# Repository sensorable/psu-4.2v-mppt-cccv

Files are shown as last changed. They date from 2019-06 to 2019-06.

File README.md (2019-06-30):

# MPPT 4.2v Li-Ion charger and SBC PSU
#### For use with Sensorable Open Source Camera v.1

The PSU board combines an MPPT (Multiple Point Power Tracking) solar charger, 4.2v battery IO port and a protected 4.2v output to power the main camera board.

 > This design has been **assembled with PCBA and successfully used** in temperate climate for over a year. 

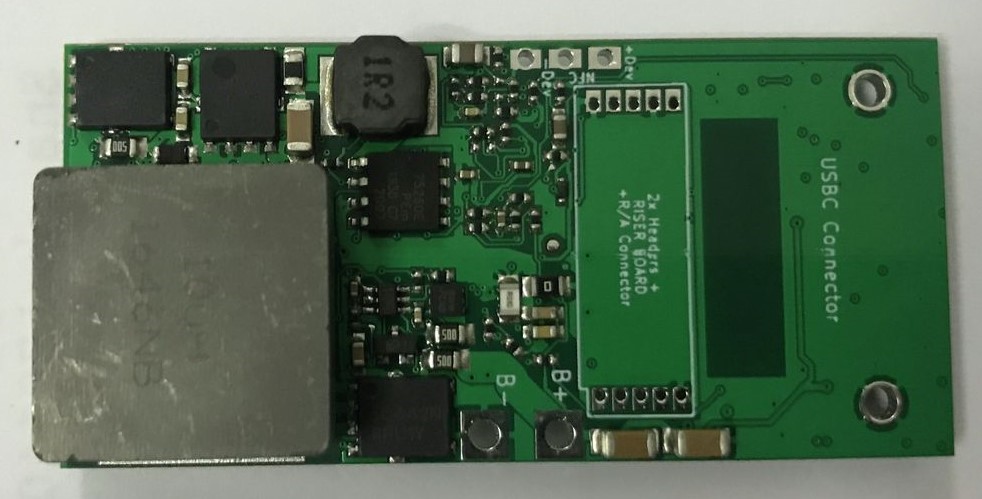
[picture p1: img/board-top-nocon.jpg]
top-nocon
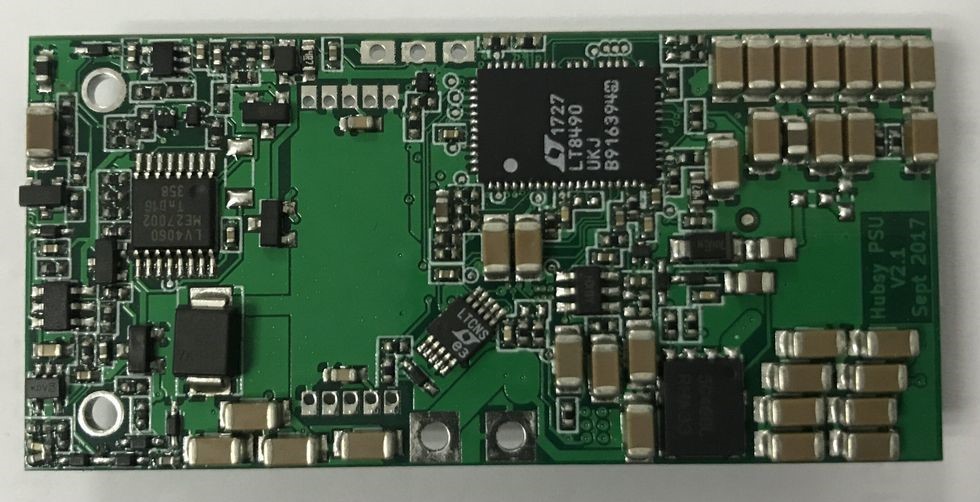
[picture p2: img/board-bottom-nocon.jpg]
bottom-nocon
 

## Specification

* **Max input working voltage:** 24V
* **Min input working voltage:** 12v
* **Max input current:** 2.5A
* **Max output current:** 6.5A
* **Max operating current:** 2A
* **Ripple:** <50mVpp nominal steady state
* **Size**: 65mm x 27mm x 15mm

#### Protection

* **Shunt Input protection:** Bipolar Zener diode, 24V working voltage, clamps to 38.9V @ 15.5A; For ESD and shunt of high-voltage surges. First line of defence. 
* **Series Input protection:** 24V working voltage 31.6V clamp, 2.5A max current. Series FETs and associated circutry will: 
Block reverse voltage. Limit current during hot-plug (for no sparks) and during surges. 
If prolonged over-voltage surge is detected charger is disabled (w/ auto-restart after surge passes) to limit power dissipated in series FETs. 
Precision over-voltage clamp (31.6V) protects switching FETs from over-voltage.  
* **Overload protection, Vbat:** None, rely on BMS. Charge current and voltage is limited by charger. 
* **Overload protection, Vout:** 4A lim; 4.5ms time constant. Retry after >500ms. Short-circuit safe.
* **Reverse polarity protection, Vin:** Safe DC voltage of +/-24V.
* **Reverse polarity protection, Vbat:** None. Charger will not attempt to charge a reversed battery but other electronics would be damaged. Batt reverse protection must be placed on BMS. 
* **Overheating protection:** Charge only when safe for Li-Ion 0C-45C, and adjust current/voltage based on temp (LT8490 feature). 
* **Electrostatic protection:** ESD/Surge protection on Input voltage, Heartbeat input, Battery voltage, Device voltage. 

## Overview

The PSU is built around [LT8490](https://www.analog.com/en/products/lt8490.html) buck-boost switching regulator battery charger with CC/CV modes and MPPT for solar input.

The purpose of the PSU is to provide a compromise between fast charging and efficient low light charging a 4P/5P/6P Li-Ion battery pack powering the main board.
The PSU incurs more losses during charging (18v -> 4.2v) to minimizes losses during discharge (4.2v direct output).
`Vout` port has an analog restart circuit for a hard reboot of the main device every 18 - 24 hrs.

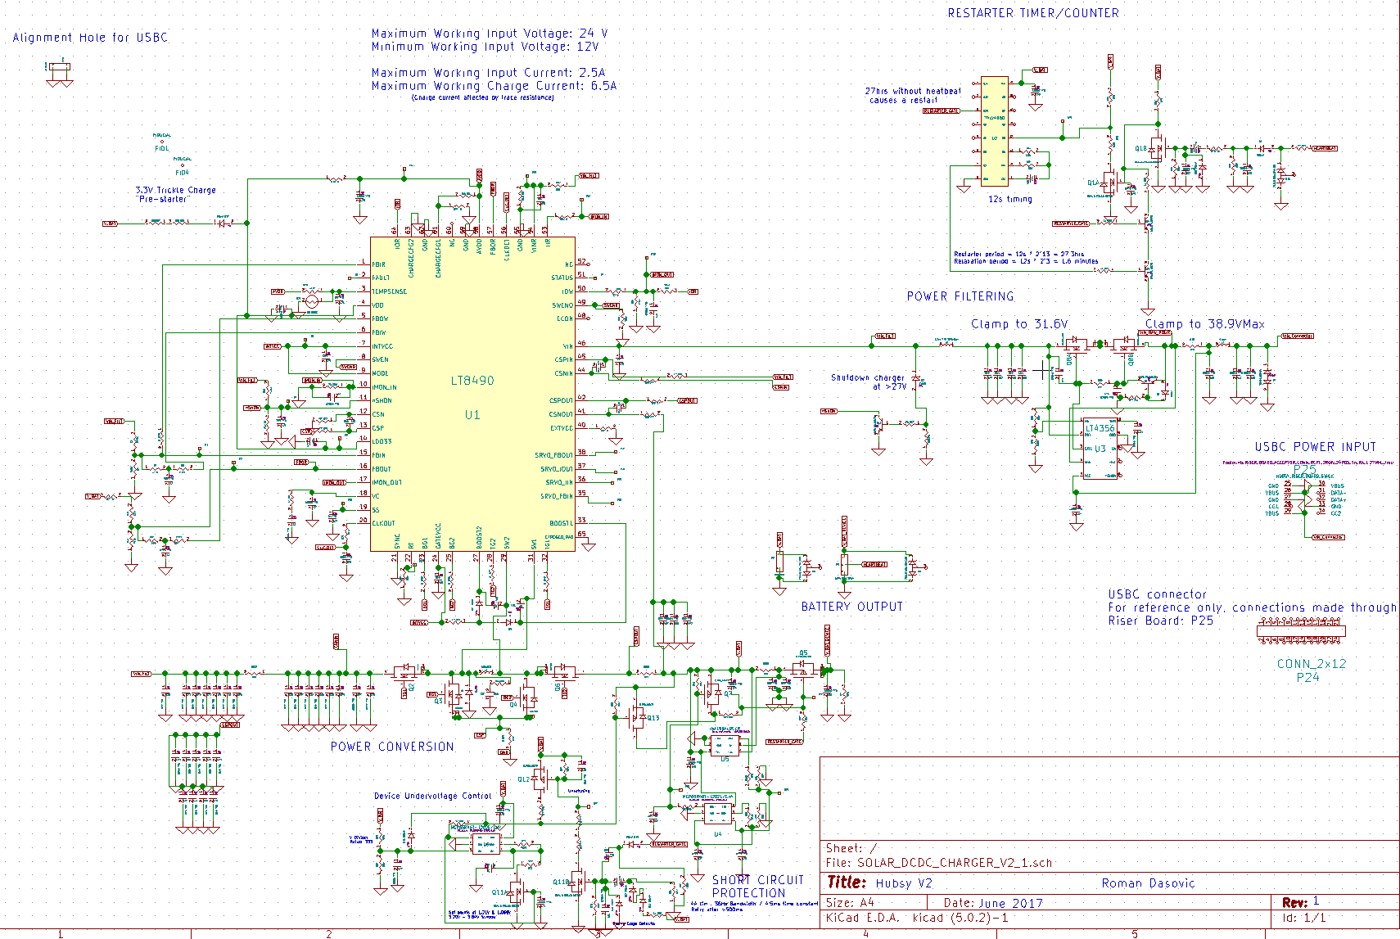
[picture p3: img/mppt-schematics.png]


#### Heat dissipation

Switching MOSFETs, the main coil and other parts of the board require heat sinking. The board itself has more copper than the electrical design requires to help dissipate the heat, but it's not enough with passive cooling inside an enclosure. Additional heat dissipation was achieved by potting the entire assembly in a metal frame with [Electrolube ER2074](https://www.electrolube.com/products/polyurethane-epoxy-resins/er2074/resins_epoxy/) epoxy resin. It produced a sealed unit that could be exposed outside the enclosure. The best result was achieved by potting the PSU inside a standard size Al U-channel.

## Features

#### Pre-starter

Most battery protection systems require external voltage to be applied for their MOSFETs to open In/Out. On the other hand, LT8490 will not attempt to charge the battery until it measures the voltage. If the battery pack gets disconnected by its protection MOSFETs it will be restarted by a 3.3V trickle charge circuit. That voltage is enough to unlock the BMS.

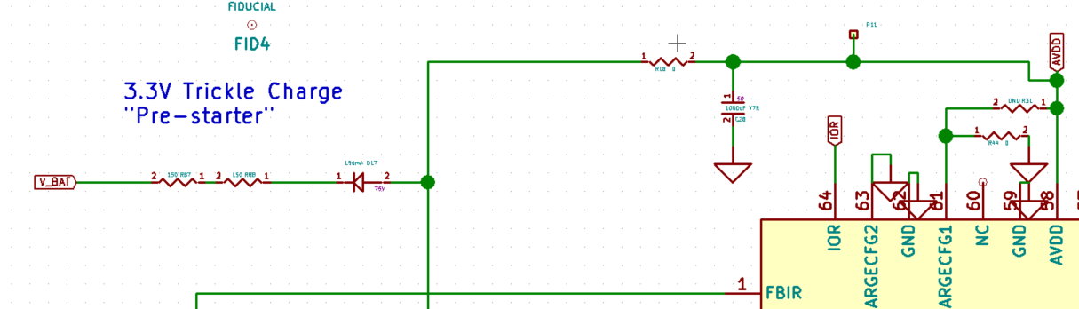
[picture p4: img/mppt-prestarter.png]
prestarter


#### Under-voltage protection

G935 board can function with Vin > 3.4v. However, the initial draw from a 3.4v battery brings the voltage down to below that. This initiates a start-abort boot cycle that drains the battery and may even damage the board. This PSU has a special undervoltage control circuit built that disables the Vout to the device until the battery voltage reaches at least 3.7v. Once operational, the device will continue until the voltage drops to 3.20V. When off, the device is latched off until the restarter circuit triggers or the battery voltage rapidly rises (a freshly inserted battery, a freshly reset BMS). 

**Consider these scenarios:**

* battery connected, Vbat < 3.7v -> Vout = Vbat momentarily, then latches off to Vout = 0V. 
* battery connected, Vbat > 3.7v -> Vout = Vbat; operational
* battery discharging, 3.2v < Vbat < 3.7v -> Vout = Vbat; operational
* battery discharging, reboot, Vbat < 3.7v -> Vout = Vbat momentarily, then latches off to Vout = 0V. 
* battery charged to 3.7v, reboot -> Vout = Vbat; operational

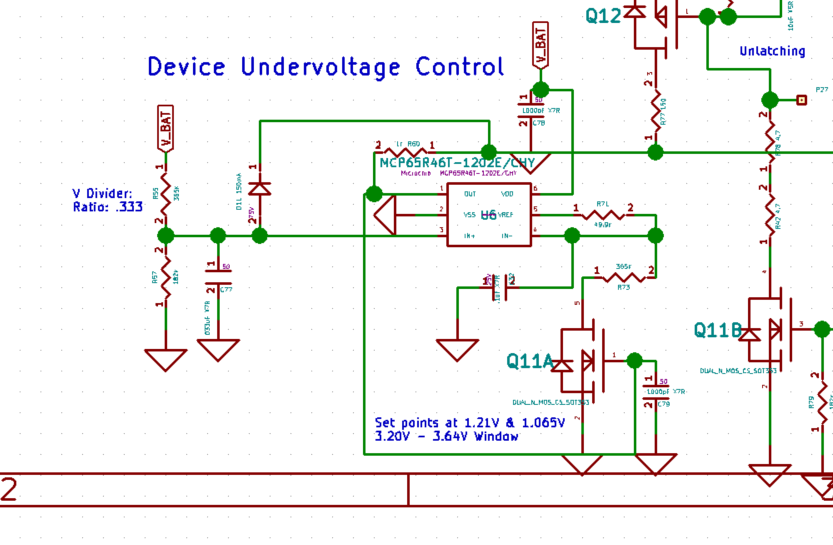
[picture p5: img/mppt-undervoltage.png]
undervoltage


#### Restarter

Given the remote nature of the PSU deployment a **hard reboot** on a schedule (approx every 27hrs) safeguards from the main board freezing for whatever reason. It is the equivalent of turning the power off for a few seconds. 

A restarter **heartbeat** wire (P3.2) can be connected to an NFC pin on G935 boards to prevent the restart. When NFC is enabled G935 sends a short burst of pulses to the restarter resetting the timer.

**Heartbeat signal requirements:** Rising edge or edges (such as sine waves from NFC) with >2V positive peaks. Must be present for >1ms.  Then, must relax for  2s < t << 27 hrs.  For example, send a 1ms NFC pulse every 5s/5min/5hour. 
Can also be operated with DC with similar timing/voltage requirements.  
Will not work with consistent output, must be pulsed.  

#### Connectors

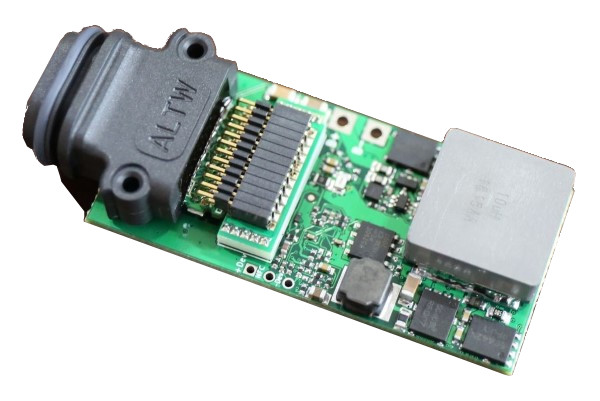
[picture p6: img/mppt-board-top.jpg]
board-top
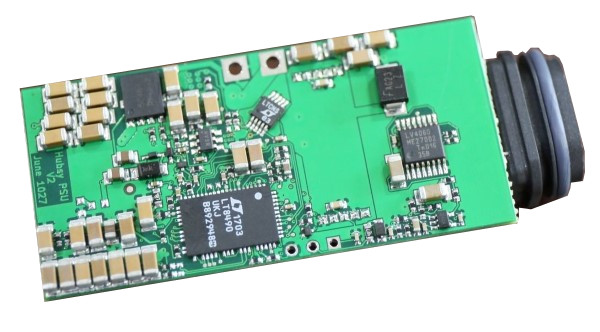
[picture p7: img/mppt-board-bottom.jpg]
board-bottom
 

#### IP68 USB-C connector

 input from a solar panel or a wall charger. This connector provides a sealed connection up to 2A per contact and remains waterproof when decoupled. Amphenol LTW part number: UC-31PFFP-QS8001. Mates with UC-20AMM-QA8A01 or similar.

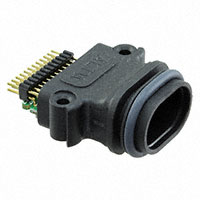
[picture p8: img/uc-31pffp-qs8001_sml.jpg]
usbc
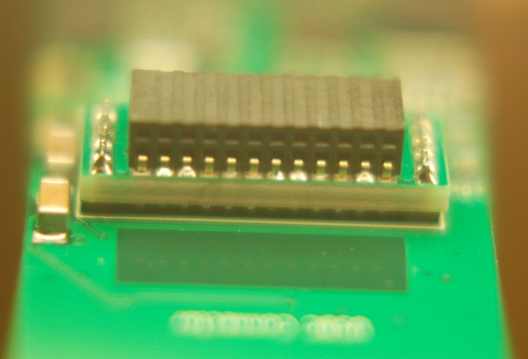
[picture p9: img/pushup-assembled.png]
pushup
 

**Pushup board:** the angle of the USB-C connector didn't allow mounting it directly on the PSU board, so we had to use a separate riser (push-up) board to align it with the enclosure. 

 > **We recommend using a simpler and cheaper external connector in your design.**

Field notes: 
* the connector proved to be reliable over 2 years of use with low mating cycles
* make sure the air was pushed out when inserting - it may push the male out
* using a plug is recommended if not coupled to stop fouling the contacts
* plugging in a USB-C charger won't work because the starting voltage is < 6v and the board don't have the means to negotiate a higher Vin. 

#### Other connectors

**4.2v battery contacts**: use 17AWG - 13AWG wires or D < 1.8mm to connect the battery pack. Must be soldered.

**4.2v device power**: use 22AWG - 17AWG wires or D < 1.2mm to connect the main board. Must be soldered.

[photo]: img/mppt-schematics.png
[board-top]: img/mppt-board-top.jpg
[board-bottom]: img/mppt-board-bottom.jpg
[input-filter]: img/mppt-input-filter.png
[usbc]: img/uc-31pffp-qs8001_sml.jpg
[prestarter]: img/mppt-prestarter.png
[undervoltage]: img/mppt-undervoltage.png
[pushup]: img/pushup-assembled.png
[top-nocon]: img/board-top-nocon.jpg
[bottom-nocon]: img/board-bottom-nocon.jpg

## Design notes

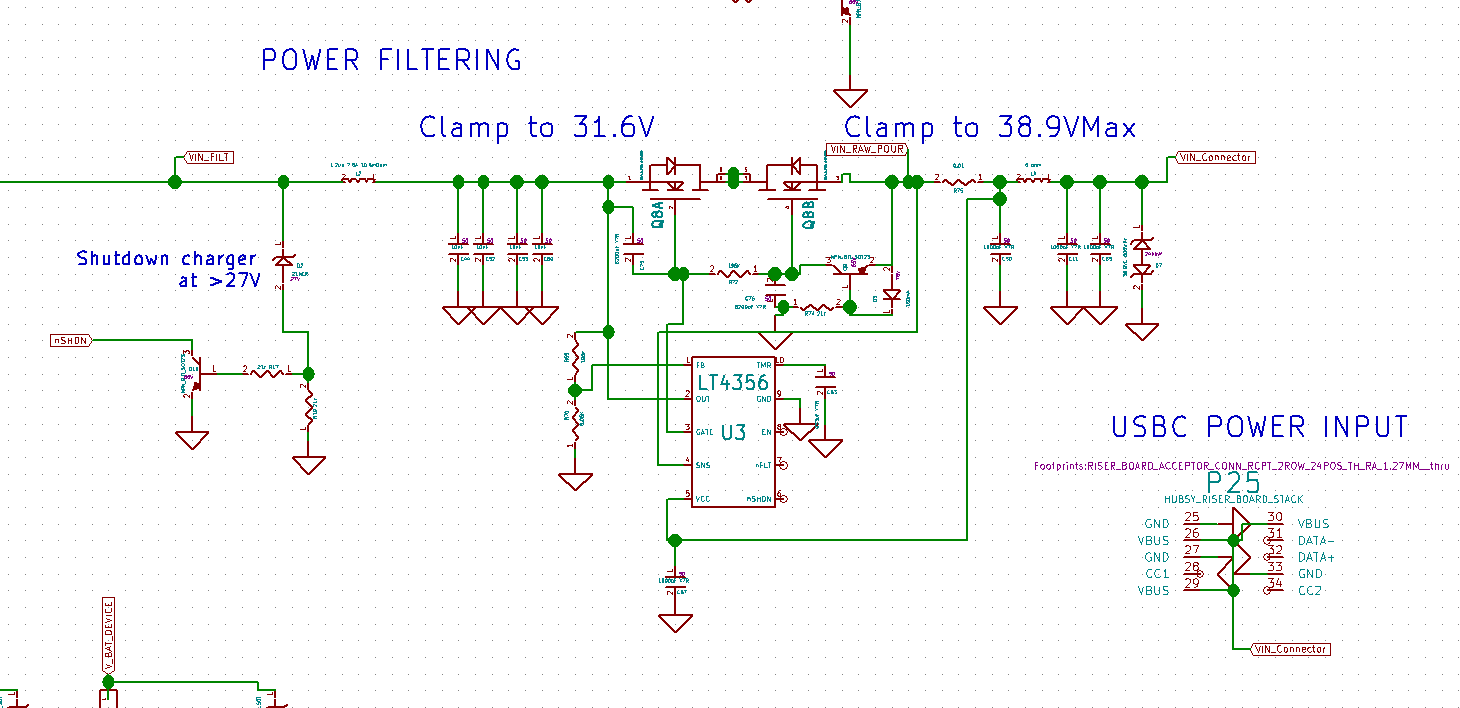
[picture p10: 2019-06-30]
img/mppt-input-filter.png

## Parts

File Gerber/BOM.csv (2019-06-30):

Item ID | Reference | Quantity | Value | Footprint | Manufacturer1 | Manufacturer1PartNumber
1 | R1,R70,R67 | 3 | 8.06k | 0402_Medium_pads | Yageo | RC0402FR-078K06L
2 | R3,R26 | 2 | 95.3K | 0402_Medium_pads | Yageo | RC0402FR-0795K3L
3 | R4 | 1 | 6.98k | 0402_Medium_pads | Yageo | RC0402FR-076K98L
4 | R5 | 1 | 14.3k | 0402_Medium_pads | Yageo | RC0402FR-0714K3L
5 | R6 | 1 | 2.87k | 0402_Medium_pads | Yageo | RC0402FR-072K87L
6 | R10 | 1 | 137k | 0402_Medium_pads | Yageo | RC0402FR-07137KL
7 | R11,R71 | 2 | 49.9k | 0402_Medium_pads | Yageo | RC0402FR-0749K9L
8 | R12 | 1 | 215k | 0402_Medium_pads | Yageo | RC0402FR-07215KL
9 | R14 | 1 | 42.2k | 0402_Medium_pads | Yageo | RC0402FR-0742K2L
10 | R33,R58 | 2 | 32.4k | 0402_Medium_pads | Yageo | RC0402FR-0732K4L
11 | R34 | 1 | 97.6k | 0402_Medium_pads | Yageo | RC0402FR-0797K6L
12 | R40 | 1 | 0.022 | 0805_Medium_Pads | Panasonic | ERJ-6BWFR022V
13 | R35,R36,R39,R37,R22,R23,R78,R42 | 8 | 4.7 | 0402_Medium_pads | Yageo | RC0402FR-074R7L
14 | R31,C10,C15,R63,C17,C59,P3,R64,P5,C13,P20,P21,P22,P12,P13,P10,P4,P2,P11,P8,P1,P14,P23,P6,P7,P15,P9,P19,P16,P17,P18,P26,P27 | 0 | DNU | DNU | DNU | DNU
15 | R20,R29 | 2 | 11.5k | 0402_Medium_pads | Yageo | RC0402FR-0711K5L
16 | R15 | 1 | 71.5K | 0402_Medium_pads | Yageo | RC0402FR-0771K5L
17 | R25 | 1 | 53.6k | 0402_Medium_pads | Yageo | RC0402FR-0753K6L
18 | R32,R41,R66 | 3 | 0.005 | 0805_Medium_Pads | Bourns | CRF0805-FZ-R005ELF
19 | C33,C31,C25,C18 | 4 | 1uF | 0805_Medium_Pads | Taiyo Yuden | UMK212BJ105KG-T
20 | C23,C30,C22,C3,C9,C19,C20,C37,C60,C53,C52,C44,C34,C43,C45,C38,C42,C56,C61,C54,C66,C64,C57,C29,C73,C72,C71,C69,C36,C14,C68,C70,C12,C80 | 34 | 10uF | 1206_Medium_Pads | Murata | GRT31CR61H106ME01L
21 | C51 | 1 | 47uF | 1206_Medium_Pads | TDK | C3216X5R0J476M160AC
22 | R62,R28,R45 | 3 | 100k | 0402_Medium_pads | Yageo | RC0402FR-07100KL
23 | R2,R76,R60,R80,R89,R86,R85 | 7 | 1k | 0402_Medium_pads | Yageo | RC0402FR-071KL
24 | C27,C35,C58,C63,C77 | 5 | .033uF X7R | 0603_Medium_Pads | Samsung | CL10B333KB8NNNC
25 | R50,R68,R48,R46,R61,R69,R72,R27,R56,R65,R83 | 11 | 196k | 0402_Medium_pads | Yageo | RC0402FR-07196KL
26 | R44,R51,R18,R30,R38,R47,R49,R52,R13 | 9 | 0 | 0402_Medium_pads | Yageo | RC0402JR-070RL
27 | R8,R74,R16,R17,R19 | 5 | 21k | 0402_Medium_pads | Yageo | RC0402FR-0721KL
28 | R59 | 1 | 3.01k | 0402_Medium_pads | Yageo | RC0402FR-073K01L
29 | C2,C5 | 2 | .33uF X7R | 0603_Medium_Pads | TDK | CGA3E3X7R1E334K080AB
30 | C26,C39 | 2 | .068uF X7R | 0402_Medium_pads | Murata | GRM155R71H683KE14D
31 | C1,C55,C41,C47 | 4 | .047uF X7R | 0402_Medium_pads | Murata | GRM155R71E473KA88D
32 | C50,C65,C11 | 3 | 1000pF X7R | 0603_Medium_Pads | AVX | 06035C102KAT2A
33 | L1 | 1 | INDUCTOR | 17.5x17.5mm_FullPads_2.1mmWide | Vishay Dale | IHLP6767GZER100M51
34 | L2 | 1 | 1.2uH 7.5A 10.5mOhm | 6.3x6.3mm_Inductor | Bourns Inc | SRN6045TA-1R2Y
35 | L4 | 1 | 0 ohm | 0805_Medium_Pads | Yageo | RC0805JR-070RL
36 | U2 | 1 | 74LV4060 | TSSOP-16_SOT403-1_5x4.4mm_.65mmPITCH | Nexperia | 74LV4060PW,112
37 | U1 | 1 | LT8490 | LT8490_QFN-64_UKJ | Linear Tech | LT8490EUKJ#PBF
38 | D7 | 1 | 38.9VC 600WPk | SMB | LittelFuse | SMBJ24CA
39 | U3 | 1 | LT4356 | MSOP-8_3x3mm_.5mmPITCH | Linear Tech | LT4356IMS-1#TRPBF
40 | Q8 | 1 | DUAL_N_MOS_LFPAK56D | LFPAK56D-8_5.2x4.6mm_1.27mm | Nexperia | BUK7K52-60EX
41 | R75 | 1 | 0.01 | 0805_Medium_Pads | Samsung | RU2012FR010CS
42 | Q9,Q10,Q15,Q14 | 4 | NPN_BJT_SOT23 | SOT-723_1.2x.8mm | ON Semiconductor | BC846BM3T5G
43 | D6 | 1 | 500mA | SOD-323 | Diodes INC | BAT54WS-7-F
44 | Q5 | 1 | P_MOS_SOT363 | SC-70-6_POWERPAK | Vishay | SIA427DJ-T1-GE3
45 | D1 | 1 | 1A | SOD-323 | Nexperia | PMEG4010EJ,115
46 | D5 | 1 | 1A | SOD-123F | Fairchild/ON | US1AFA
47 | C67,C40,C62,C49,C48,C7,C28,C4,C46,C74,C78,C79 | 12 | 1000pF X7R | 0402_Medium_pads | KEMET | C0402C102K5RACTU
48 | FID1,FID4 | 0 | FIDUCIAL | FIDUCIAL_.75mm | FIDUCIAL | FIDUCIAL
49 | D3,D4,D11,D12,D14,D13,D15,D16,D17 | 9 | 150mA | SOD-523F | Fairchild/ON | 1N4148WT
50 | R9 | 1 | 1k | 0402_Medium_pads | Yageo | RC0402JR-071KL
51 | C6 | 1 | .033uF X7R | 0402_Medium_pads | Yageo | CC0402KRX7R8BB333
52 | C24,C82,C83,C32,C21 | 5 | .1uF X7R | 0402_Medium_pads | Taiyo Yuden | TMK105BJ104KV-F
53 | Q1,Q11 | 2 | DUAL_N_MOS_CS_SOT353 | SOT-353-5pin_2x1.25mm_.65mmPITCH | Diodes Inc | DMN32D2LDF-7
54 | R7,R55,R73 | 3 | 365k | 0402_Medium_pads | Yageo | RC0402FR-07365KL
55 | R43,R24 | 2 | 4.7 | 0603_Medium_Pads | Yageo | RC0603FR-074R7L
56 | Q3,Q6 | 2 | N_MOS_5-DFN | DFN5_SO8FL | On Semiconductor | NTMFS5C442NT1G
57 | Q2,Q4 | 2 | N_MOS_5-DFN | DFN5_SO8FL | ON Semiconductor | NTMFS5C468NLT1G
58 | U5 | 1 | INA199A1DCKR | SOT-363(SC-70)-6pin_2x1.25mm_.65mmPITCH | Texas Instruments | INA199A1DCKR
59 | U4,U6 | 2 | MCP65R46T-1202E/CHY | SOT23-6 | Microchip | MCP65R46T-1202E/CHY
60 | C8,C16,C75,C76,C81 | 5 | 8200pF X7R | 0402_Medium_pads | Samsung | CL05B822KB5NNNC
61 | D2 | 1 | ZENER | VMD2 | Rohm | VDZT2R27B
62 | P24 | 1 | CONN_2x12 | Amphenol-UC-31PFFP-QS8001-USB-Connectors-USB-3.1-TYPE-C-JACK | Amphenol | UC-31PFFP-QS8001
63 | P25 | 1 | HUBSY_RISER_BOARD_STACK | RISER_BOARD_ACCEPTOR_CONN_RCPT_2ROW_24POS_TH_RA_1.27MM__thru | Harwin+Hubsy | 2xM50-3530542+HubsyRiserBoardV2.1+M50-3201245
64 | R21 | 1 | 10k 3380K | 0603_Medium_Pads | Epcos (TDK) | B57330V2103F260
65 | D8,D9,D10 | 3 | ZENER_BiDir_3pin_SOT | SOT-23 | On Semiconductor | MMBZ5V6ALT3G
66 | R57,R79,R81,R54,R84 | 5 | 182k | 0402_Medium_pads | Yageo | RC0402FR-07182KL
67 | R77,R82,R53,R87,R88 | 5 | 150 | 0402_Medium_pads | Yageo | RC0402FR-07150RL
68 | Q12,Q7,Q13 | 3 | P_MOS_SOT23 | SST3 | Rohm | RSC002P03T316

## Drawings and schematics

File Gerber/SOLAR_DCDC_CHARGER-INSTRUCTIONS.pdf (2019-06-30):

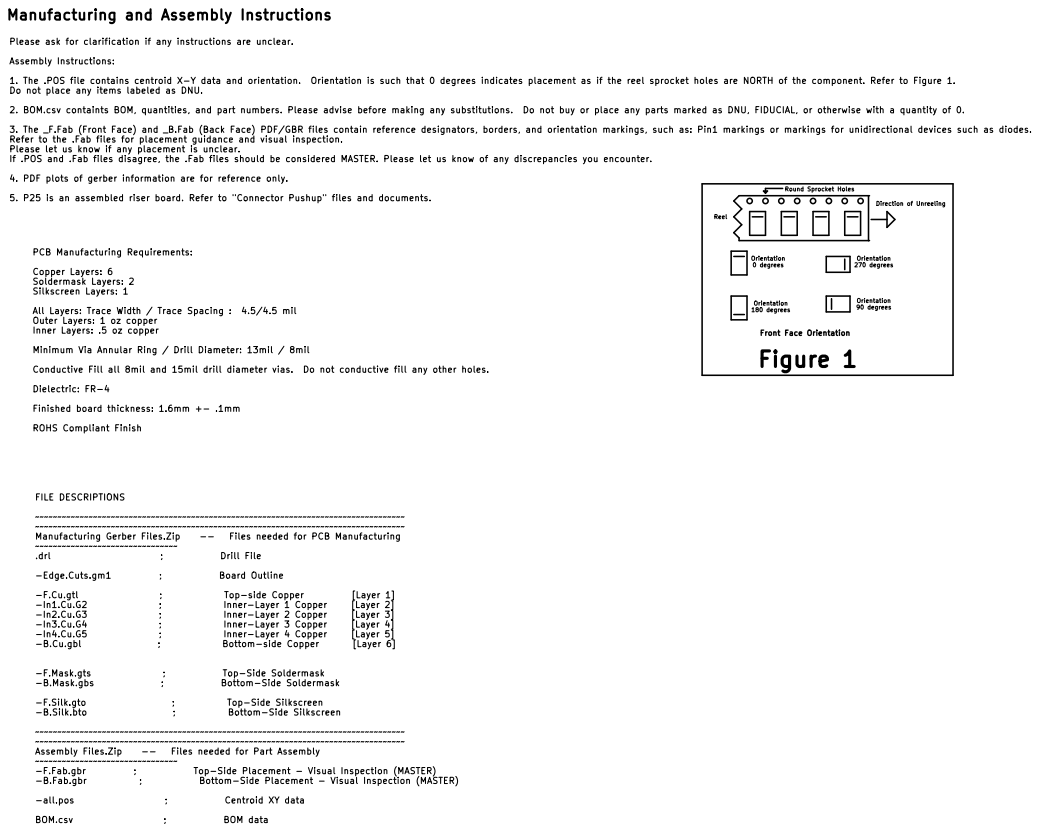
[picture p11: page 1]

Round Sprocket Holes Front Face Orientation Please ask for clarification if any instructions are unclear. Assembly Instructions: 1. The .POS file contains centroid X-Y data and orientation. Orientation is such that 0 degrees indicates placement as if the reel sprocket holes are NORTH of the component. Refer to Figure 1. Do not place any items labeled as DNU. 2. BOM.csv containts BOM, quantities, and part numbers. Please advise before making any substitutions. Do not buy or place any parts marked as DNU, FIDUCIAL, or otherwise with a quantity of 0. 3. The _F.Fab (Front Face) and _B.Fab (Back Face) PDF/GBR files contain reference designators, borders, and orientation markings, such as: Pin1 markings or markings for unidirectional devices such as diodes. Refer to the .Fab files for placement guidance and visual inspection. Please let us know if any placement is unclear.

PCB Manufacturing Requirements: Copper Layers: 6 Soldermask Layers: 2 Silkscreen Layers: 1 All Layers: Trace Width / Trace Spacing : 4.5/4.5 mil Outer Layers: 1 oz copper

Inner Layers: .5 oz copper Minimum Via Annular Ring / Drill Diameter: 13mil / 8mil Conductive Fill all 8mil and 15mil drill diameter vias. Do not conductive fill any other holes. Dielectric: FR-4 Finished board thickness: 1.6mm +- .1mm

FILE DESCRIPTIONS Manufacturing Gerber Files.Zip -- Files needed for PCB Manufacturing

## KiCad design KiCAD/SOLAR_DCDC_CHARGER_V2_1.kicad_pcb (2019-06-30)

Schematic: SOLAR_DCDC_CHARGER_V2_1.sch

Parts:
C1, C41, C47, C55: .047uF X7R; 0402_Medium_pads; Voltage 25V; Manufacturer1PartNumber GRM155R71E473KA88D
C2, C5: .33uF X7R; 0603_Medium_Pads; Voltage 25V; Manufacturer1PartNumber CGA3E3X7R1E334K080AB
C3, C9, C12, C14, C19, C20, C29, C34, C36, C37, C38, C42, C43, C45, C54, C56, C57, C61, C64, C66, C68, C69, C70, C71, C72, C73, C80: 10uF X5R; 1206_Medium_Pads; Voltage 50; Manufacturer1PartNumber GRT31CR61H106ME01L
C4, C7, C28, C40, C46, C48, C49, C62, C67, C74, C78, C79: 1000pF X7R; 0402_Medium_pads; Voltage 50; Manufacturer1PartNumber CC0402KRX7R9BB102
C6: .033uF X7R; 0402_Medium_pads; Voltage 25V; Manufacturer1PartNumber CC0402KRX7R8BB333
C8, C16, C75, C76, C81: 8200pF X7R; 0402_Medium_pads; Voltage 50; Manufacturer1PartNumber CL05B822KB5NNNC
C10, C13, C15: DNU; 0402_Medium_pads; Voltage V; Manufacturer1PartNumber MFG1PN
C11, C50, C65: 1000pF X7R; 0603_Medium_Pads; Voltage 50; Manufacturer1PartNumber 06035C102KAT2A
C17: DNU; 0603_Medium_Pads; Voltage V; Manufacturer1PartNumber MFG1PN
C18, C25, C31, C33: 1uF; 0805_Medium_Pads; Voltage 50; Manufacturer1PartNumber UMK212BJ105KG-T
C21, C24, C32, C82, C83: .1uF X7R; 0402_Medium_pads; Voltage 25V; Manufacturer1PartNumber GRM155R61E104KA87D
C22, C23, C30, C44, C52, C53, C60: 10uF; 1206_Medium_Pads; Voltage 50; Manufacturer1PartNumber GRT31CR61H106ME01L
C26, C39: .068uF X7R; 0402_Medium_pads; Voltage 50V; Manufacturer1PartNumber GRM155R71H683KE14D
C27, C35, C58, C63, C77: .033uF X7R; 0603_Medium_Pads; Voltage 50; Manufacturer1PartNumber CL10B333KB8NNNC
C51: 47uF; 1206_Medium_Pads; Voltage 6.3V; Manufacturer1PartNumber GRM31CR60J476KE19L
C59: DNU; 0402_Medium_pads; Voltage 50; Manufacturer1PartNumber MFG1PN
D1: 1A; SOD-323; Voltage 50V; Manufacturer1PartNumber \"PMEG4010EJ,115\"
D2: ZENER; VMD2; Voltage 27V; Manufacturer1PartNumber VDZT2R27B
D3, D4, D11, D12, D13, D14, D15, D16, D17: 150mA; SOD-523F; Voltage 75V; Manufacturer1PartNumber 1N4148WT
D5: 1A; SOD-123F; Voltage 50V; Manufacturer1PartNumber US1AFA
D6: 500mA; SOD-323; Voltage 30V; Manufacturer1PartNumber BAT54WS-7-F
D7: 38.9VC 600WPk; SMB; Voltage 24VWM; Manufacturer1PartNumber SMBJ24CA
D8, D9, D10: ZENER_BiDir_3pin_SOT; SOT-23; Voltage V; Manufacturer1PartNumber MMBZ5V6ALT3G
FID1, FID4: FIDUCIAL; FIDUCIAL_.75mm; Manufacturer1PartNumber FIDUCIAL
L1: INDUCTOR; 17.5x17.5mm_FullPads_2.1mmWide; Manufacturer1PartNumber IHLP6767GZER100M51
L2: 1.2uH 7.5A 10.5mOhm; 6.3x6.3mm_Inductor; Manufacturer1PartNumber SRN6045TA-1R2Y
L4: 0 ohm; 0805_Medium_Pads; Manufacturer1PartNumber RC0805JR-070RL
P1, P2, P4, P6, P7, P8, P9, P10, P11, P12, P13, P14, P15, P16, P17, P18, P19, P20, P21, P22, P23, P27: PAD; Manufacturer1PartNumber MFG1PN
P3: Conn_Basic_3_pin; CONN_3pin_just_holes_2.5mmPITCH_.72mm-1.15mmHOLES; Manufacturer1PartNumber MFG1PN
P5: Conn_Basic_2_pin; Conn_2_3x3mm_4.7mmpitch_w_1.7mm_drill; Manufacturer1PartNumber MFG1PN
P24: CONN_2x12; Amphenol-UC-31PFFP-QS8001-USB-Connectors-USB-3.1-TYPE-C-JACK; Manufacturer1PartNumber UC-31PFFP-QS8001
P25: HUBSY_RISER_BOARD_STACK; RISER_BOARD_ACCEPTOR_CONN_RCPT_2ROW_24POS_TH_RA_1.27MM__thru; Manufacturer1PartNumber 2xM50-3530542+HubsyRiserBoardV2.1+M50-3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
P26: Conn_Basic_2_pin; ALIGNMENT_HOLES_2x_2.8mmx2.0mm_20mmPitch; Manufacturer1PartNumber MFG1PN
Q1, Q11: DUAL_N_MOS_CS_SOT353; SOT-353-5pin_2x1.25mm_.65mmPITCH; Manufacturer1PartNumber DMN32D2LDF-7
Q2, Q4: N_MOS_5-DFN; DFN5_SO8FL; Manufacturer1PartNumber NTMFS5C468NLT1G
Q3, Q6: N_MOS_5-DFN; DFN5_SO8FL; Manufacturer1PartNumber NTMFS5C442NT1G
Q5: P_MOS_SOT363; SC-70-6_POWERPAK; Manufacturer1PartNumber SIA427DJ-T1-GE3
Q7, Q12, Q13: P_MOS_SOT23; SST3; Manufacturer1PartNumber RSC002P03T316
Q8: DUAL_N_MOS_LFPAK56D; LFPAK56D-8_5.2x4.6mm_1.27mm; Manufacturer1PartNumber BUK7K52-60EX
Q9, Q10, Q14, Q15: NPN_BJT_SOT23; SOT-723_1.2x.8mm; Voltage 65V; Manufacturer1PartNumber BC846BM3T5G
R1, R67, R70: 8.06k; 0402_Medium_pads; Tolerance 1%; Manufacturer1PartNumber RC0402FR-078K06L
R2, R60, R76, R80, R85, R86, R89: 1k; 0402_Medium_pads; Tolerance 1%; Manufacturer1PartNumber RC0402FR-071KL
R3, R26: 95.3K; 0402_Medium_pads; Tolerance 1%; Manufacturer1PartNumber RC0402FR-0795K3L
R4: 6.98k; 0402_Medium_pads; Tolerance 1%; Manufacturer1PartNumber RC0402FR-076K98L
R5: 14.3k; 0402_Medium_pads; Tolerance 1%; Manufacturer1PartNumber RC0402FR-0714K3L
R6: 2.87k; 0402_Medium_pads; Tolerance 1%; Manufacturer1PartNumber RC0402FR-072K87L
R7, R55, R73: 365k; 0402_Medium_pads; Tolerance 1%; Manufacturer1PartNumber RC0402FR-07365KL
R8, R16, R17, R19, R74: 21k; 0402_Medium_pads; Tolerance 1%; Manufacturer1PartNumber RC0402FR-0721KL
R9: 1k; 0402_Medium_pads; Tolerance 1%; Manufacturer1PartNumber RC0402JR-071KL
R10: 137k; 0402_Medium_pads; Tolerance 1%; Manufacturer1PartNumber RC0402FR-07137KL
R11, R71: 49.9k; 0402_Medium_pads; Tolerance 1%; Manufacturer1PartNumber RC0402FR-0749K9L
R12: 215k; 0402_Medium_pads; Tolerance 1%; Manufacturer1PartNumber RC0402FR-07215KL
R13, R18, R30, R38, R44, R47, R49, R51, R52: 0; 0402_Medium_pads; Tolerance 1%; Manufacturer1PartNumber RC0402JR-070RL
R14: 42.2k; 0402_Medium_pads; Tolerance 1%; Manufacturer1PartNumber RC0402FR-0742K2L
R15: 71.5K; 0402_Medium_pads; Tolerance 1%; Manufacturer1PartNumber RC0402FR-0771K5L
R20, R29: 11.5k; 0402_Medium_pads; Tolerance 1%; Manufacturer1PartNumber RC0402FR-0711K5L
R21: 10k 3380K; 0603_Medium_Pads; Tolerance Tol; Manufacturer1PartNumber B57330V2103F260
R22, R23, R35, R36, R37, R39, R42, R78: 4.7; 0402_Medium_pads; Tolerance 1%; Manufacturer1PartNumber RC0402FR-074R7L
R24, R43: 4.7; 0603_Medium_Pads; Tolerance 1%; Manufacturer1PartNumber RC0603FR-074R7L
R25: 53.6k; 0402_Medium_pads; Tolerance 1%; Manufacturer1PartNumber RC0402FR-0753K6L
R27, R46, R48, R50, R56, R61, R65, R68, R69, R72, R83: 196k; 0402_Medium_pads; Tolerance 1%; Manufacturer1PartNumber RC0402FR-07196KL
R28, R45, R62: 100k; 0402_Medium_pads; Tolerance 1%; Manufacturer1PartNumber RC0402FR-07100KL
R31, R64: DNU; 0402_Medium_pads; Tolerance 1%; Manufacturer1PartNumber MFG1PN
R32, R41, R66: 0.005; 0805_Medium_Pads; Tolerance 5%; Manufacturer1PartNumber CRF0805-FZ-R005ELF
R33, R58: 32.4k; 0402_Medium_pads; Tolerance 1%; Manufacturer1PartNumber RC0402FR-0732K4L
R34: 97.6k; 0402_Medium_pads; Tolerance 1%; Manufacturer1PartNumber RC0402FR-0797K6L
R40: 0.022; 0805_Medium_Pads; Tolerance 1; Manufacturer1PartNumber ERJ-6BWFR022V
R53, R77, R82, R87, R88: 150; 0402_Medium_pads; Tolerance 1%; Manufacturer1PartNumber RC0402FR-07150RL
R54, R57, R79, R81, R84: 182k; 0402_Medium_pads; Tolerance 1%; Manufacturer1PartNumber RC0402FR-07182KL
R59: 3.01k; 0402_Medium_pads; Tolerance 1%; Manufacturer1PartNumber RC0402FR-073K01L
R63: DNU; 0603_Medium_Pads; Manufacturer1PartNumber MFG1PN
R75: 0.01; 0805_Medium_Pads; Tolerance 1; Manufacturer1PartNumber RU2012FR010CS
U1: LT8490; LT8490_QFN-64_UKJ; Manufacturer1PartNumber LT8490EUKJ#PBF
U2: 74LV4060; TSSOP-16_SOT403-1_5x4.4mm_.65mmPITCH; Manufacturer1PartNumber \"74LV4060PW,112\"
U3: LT4356; MSOP-8_3x3mm_.5mmPITCH; Manufacturer1PartNumber LT4356IMS-1#TRPBF
U4, U6: MCP65R46T-1202E/CHY; SOT23-6; Manufacturer1PartNumber MCP65R46T-1202E/CHY
U5: INA199A1DCKR; SOT-363(SC-70)-6pin_2x1.25mm_.65mmPITCH; Manufacturer1PartNumber INA199A1DCKR

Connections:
AVDD: C28.1, P11.1, R18.2, R20.2, R31.1, U1.58 (AVDD)
BG1: Q3.4, R30.2
BG2: Q4.4, R38.2
CLK_DET: C26.1, R25.1, U1.56 (CLKDET)
CSNIN: C19.1, C25.1, C27.1, C29.1, C57.1, C58.1, C64.1, C66.1, Q2.5, R35.2, R40.1
CSP: Q3.1, Q3.2, Q3.3, Q4.1, Q4.2, Q4.3, R23.2, R32.1
CSPOUT: C12.1, C14.1, C34.1, C35.1, C36.1, C43.1, C45.1, C68.1, C70.1, Q6.5, R37.2, R41.2
FBOR: P2.1, R10.1, R11.2, R12.1, U1.16 (FBOUT), U1.57 (FBOR)
GND: C1.2, C2.2, C3.2, C4.2, C5.2, C6.2, C7.2, C8.1, C9.2, C11.2, C12.2, C14.2, C16.2, C17.1, C19.2, C20.2, C21.2, C22.2, C23.2, C24.2, C25.2, C26.2, C27.2, C28.2, C29.2, C30.2, C32.1, C33.2, C34.2, C35.2, C36.2, C37.2, C38.2, C40.2, C41.2, C42.2, C43.2, C44.2, C45.2, C46.2, C47.2, C48.2, C49.2, C50.2, C52.2, C53.2, C54.2, C55.2, C56.2, C57.2, C58.2, C59.2, C60.2, C61.2, C62.2, C63.2, C64.2, C65.2, C66.2, C67.2, C68.2, C69.2, C70.2, C71.2, C72.2, C73.2, C76.1, C77.2, C78.2, C79.2, C81.2, D1.2, D7.2, D8.2, D9.2, D10.2, D15.2, D16.2, P3.3, P5.2, P25.25 (GND), P25.27 (GND), P25.33 (GND), P26.1, P26.2, Q1.2, Q10.2, Q11.2, Q15.2, R1.1, R4.1, R7.2, R8.2, R11.1, R16.2, R19.1, R21.2, R22.2, R27.1, R32.2, R34.1, R44.2, R46.1, R48.1, R52.2, R57.1, R64.1, R65.1, R68.2, R70.1, R74.1, R79.1, R81.1, R84.1, U1.21 (SYNC), U1.55 (GND), U1.59 (GND), U1.62 (GND), U1.63 (CHARGECFG2), U1.65 (EXPOSED_PAD), U2.8 (GND), U3.9 (GND), U4.2 (VSS), U5.1 (REF), U5.2 (GND), U6.2 (VSS)
HEARTBEAT: P3.2, R24.1
IMON_IN: C8.2, P14.1, R16.1, R51.2, U1.10 (IMON_IN)
IMON_OUT: C16.1, P19.1, R33.1, R34.2, R59.2, U1.17 (IMON_OUT)
INTVCC: C23.1, C30.1, P8.1, R43.2, U1.7 (INTVCC), U1.9 (MODE), U1.24 (GATEVCC)
IOR: R59.1, U1.64 (IOR)
unnamed: C1.1, R12.2, R14.1
unnamed: C2.1, R5.2, R6.1
unnamed: C6.1, R9.2
unnamed: C7.1, R9.1, U1.18 (VC)
unnamed: C10.1, R22.1, U1.12 (CSN)
unnamed: C10.2, R23.1, U1.13 (CSP)
unnamed: C13.1, R39.2, U1.45 (CSPIN)
unnamed: C13.2, R35.1, U1.44 (CSNIN)
unnamed: C15.1, R37.1, U1.42 (CSPOUT)
unnamed: C15.2, R36.1, U1.41 (CSNOUT)
unnamed: C17.2, R63.2
unnamed: C18.1, D4.1, U1.27 (BOOST2)
unnamed: C18.2, L1.1, Q4.5, Q6.1, Q6.2, Q6.3, U1.29 (SW2)
unnamed: C21.1, R20.1, R21.1, U1.3 (TEMPSENSE)
unnamed: C4.1, C22.1, D17.2, P9.1, R18.1, U1.4 (VDD), U1.14 (LDO33)
unnamed: C24.1, P10.1, U1.19 (SS)
unnamed: C31.1, D5.1, U1.33 (BOOST1)
unnamed: C31.2, D1.1, L1.2, Q2.1, Q2.2, Q2.3, Q3.5, R63.1, U1.31 (SW1)
unnamed: C32.2, R71.2, R73.2, U6.4 (IN-)
unnamed: C39.1, R76.1
unnamed: C39.2, C62.1, D16.1, Q1.3, R46.2
unnamed: C40.1, D6.1, R48.2, R76.2
unnamed: C41.1, Q1.1, Q1.4, R45.2, R89.1
unnamed: C44.1, C52.1, C53.1, C60.1, C75.1, L2.1, Q8.1, R69.2, U3.2 (OUT)
unnamed: C47.1, R58.2, R65.2, U4.3 (IN+)
unnamed: C50.1, C67.1, L4.2, R75.1, U3.5 (VCC)
unnamed: C51.1, R61.2, R62.2
unnamed: C51.2, U2.9 (CTC)
unnamed: C54.1, P20.1, Q7.1, R56.1, R82.1
unnamed: C55.1, P21.1, R26.2, R64.2, U4.4 (IN-)
unnamed: C56.1, C61.1, Q5.4, R66.1, U5.5 (IN-)
unnamed: C59.1, P13.1, R1.2, R50.2, U1.54 (VINR)
unnamed: C63.1, U3.10 (TMR)
unnamed: C74.2, P22.1, Q5.3, R53.2, R67.2
unnamed: C75.2, Q8.2, R72.2, U3.3 (GATE)
unnamed: C76.2, Q8.4, Q9.3, R72.1
unnamed: C77.1, D11.2, R55.2, R57.2, U6.3 (IN+)
unnamed: C79.1, Q11.1, R60.2, U6.1 (OUT)
unnamed: C80.2, P27.1, Q12.1, R54.1, R78.2
unnamed: C81.1, C82.2, C83.1, D15.1, Q11.3, R79.2
unnamed: C82.1, D12.1, R81.2
unnamed: C83.2, D13.1, R84.2
unnamed: D2.2, R17.1, R19.2
unnamed: D3.1, Q9.1, R74.2
unnamed: D4.2, D5.2, R43.1
unnamed: D6.2, D10.1, R24.2
unnamed: D11.1, Q13.1, R60.1, R77.1, R83.1
unnamed: D12.2, D14.1
unnamed: D14.2, R80.2
unnamed: D17.1, R88.1
unnamed: P1.1, R3.1, R4.2, R5.1, R13.2, U1.15 (FBIN)
unnamed: P6.1, U1.2 (FAULT)
unnamed: P7.1, U1.51 (STATUS)
unnamed: P12.1, R27.2, U1.22 (RT)
unnamed: P15.1, U1.36 (SRVO_IIN)
unnamed: P16.1, U1.35 (SRVO_FBIN)
unnamed: P17.1, U1.38 (SRVO_FBOUT)
unnamed: P18.1, U1.37 (SRVO_IOUT)
unnamed: P23.1, R28.2, R29.2, U2.12 (MR)
unnamed: Q1.5, R29.1
unnamed: Q8.5, Q8.8
unnamed: Q10.1, R17.2
unnamed: Q11.4, R42.1
unnamed: Q11.5, R73.1
unnamed: Q12.3, R77.2
unnamed: Q7.3, Q13.3, R53.1
unnamed: Q14.1, R86.1
unnamed: Q14.2, Q15.3
unnamed: Q14.3, R89.2
unnamed: Q15.1, R85.1
unnamed: R6.2, U1.6 (FBIW)
unnamed: R2.2, R10.2
unnamed: R13.1, U1.1 (FBIR)
unnamed: R14.2, U1.5 (FBOW)
unnamed: R25.2, U1.20 (CLKOUT)
unnamed: R26.1, U5.6 (OUT)
unnamed: R30.1, U1.23 (BG1)
unnamed: R31.2, R44.1, U1.61 (CHARGECFG1)
unnamed: R33.2, U1.50 (IOW)
unnamed: R38.1, U1.25 (BG2)
unnamed: R42.2, R78.1
unnamed: R47.1, U1.28 (TG2)
unnamed: R49.1, U1.32 (TG1)
unnamed: R51.1, U1.53 (IIR)
unnamed: R52.1, U1.40 (EXTVCC)
unnamed: R58.1, U4.5 (VREF)
unnamed: R61.1, U2.11 (RS)
unnamed: R62.1, U2.10 (RTC)
unnamed: R69.1, R70.2, U3.1 (FB)
unnamed: R71.1, U6.5 (VREF)
unnamed: R82.2, U4.1 (OUT)
unnamed: R85.2, U2.7 (Q3)
unnamed: R87.1, R88.2
RESTARTER_GATE: D13.2, R67.1, R86.2, U2.3 (Q13)
SWEN0: R68.1, U1.8 (SWEN), U1.49 (SWENO)
TG1: Q2.4, R49.2
TG2: Q6.4, R47.2
VIN_Connector: C11.1, C65.1, D7.1, L4.1, P25.26 (VBUS), P25.29 (VBUS), P25.30 (VBUS)
VIN_FILT: C3.1, C9.1, C20.1, C33.1, C69.1, C71.1, C72.1, C73.1, D2.1, L2.2, R3.2, R15.2, R39.1, R40.2, R50.1, U1.46 (VIN)
VIN_RAW_POUR: D3.2, Q8.3, Q9.2, R75.2, U3.4 (SNS)
V_BAT: C37.1, C38.1, C42.1, C46.1, C49.1, C74.1, C78.1, C80.1, D8.1, P5.1, Q7.2, Q12.2, Q13.2, R2.1, R28.1, R36.2, R41.1, R45.1, R54.2, R55.1, R56.2, R66.2, R80.1, R83.2, R87.2, U2.16 (VCC), U4.6 (VDD), U5.3 (V+), U5.4 (IN+), U6.6 (VDD)
V_BAT_DEVICE: C48.1, D9.1, P3.1, Q5.1, Q5.2, Q5.5, Q5.6, R7.1
nSHDN: C5.1, P4.1, Q10.3, R8.1, R15.1, U1.11 (nSHDN)

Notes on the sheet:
June 2017
USBC POWER INPUT
RESTARTER TIMER/COUNTER
POWER CONVERSION
BATTERY OUTPUT
POWER FILTERING
Clamp to 38.9VMax
Clamp to 31.6V
Maximum Working Input Voltage: 24 V Minimum Working Input Voltage: 12V Maximum Working Input Current: 2.5A Maximum Working Charge Current: 6.5A
Shutdown charger at >27V
12s timing
27hrs without heatbeat causes a restart
SHORT CIRCUIT PROTECTION
4A lim ; 36Hz Bandwidth / 4.5ms time constant Retry after >500ms
USBC connector For reference only, connections made through Riser Board; P25
Hubsy V2 Roman Dasovic
Alignment Hole for USBC
V Divider: Ratio: .333
Set points at 1.21V & 1.065V 3.20V - 3.64V Window
Device Undervoltage Control
Rising Edge Detector
Unlatching
Restarter period = 12s * 2^13 = 27.3hrs. Relaxation period = 12s * 2^3 = 1.6 minutes
3.3V Trickle Charge "Pre-starter"
(Charge current affected by trace resistance)

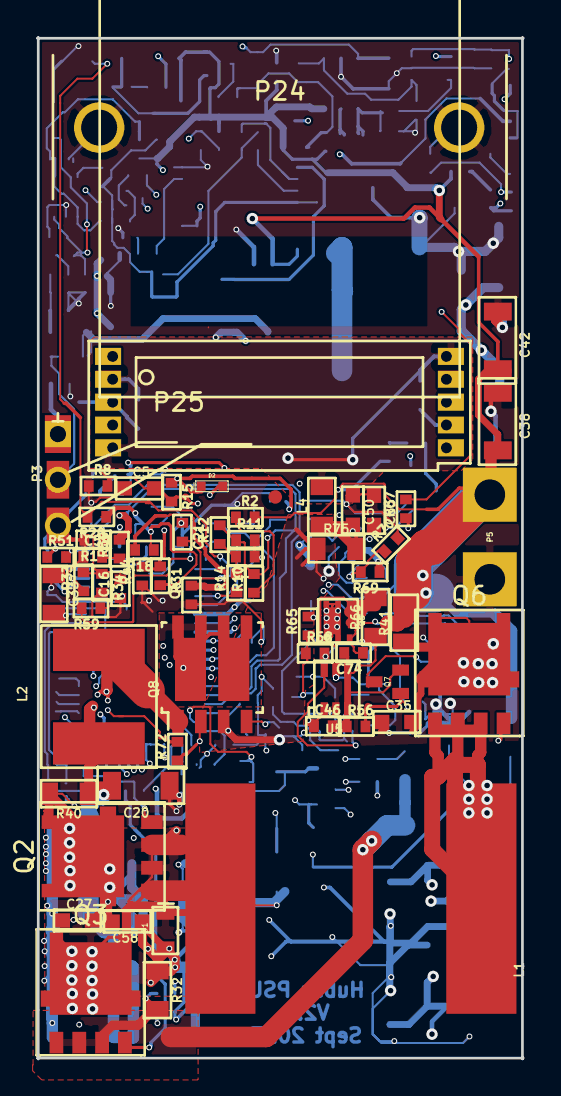
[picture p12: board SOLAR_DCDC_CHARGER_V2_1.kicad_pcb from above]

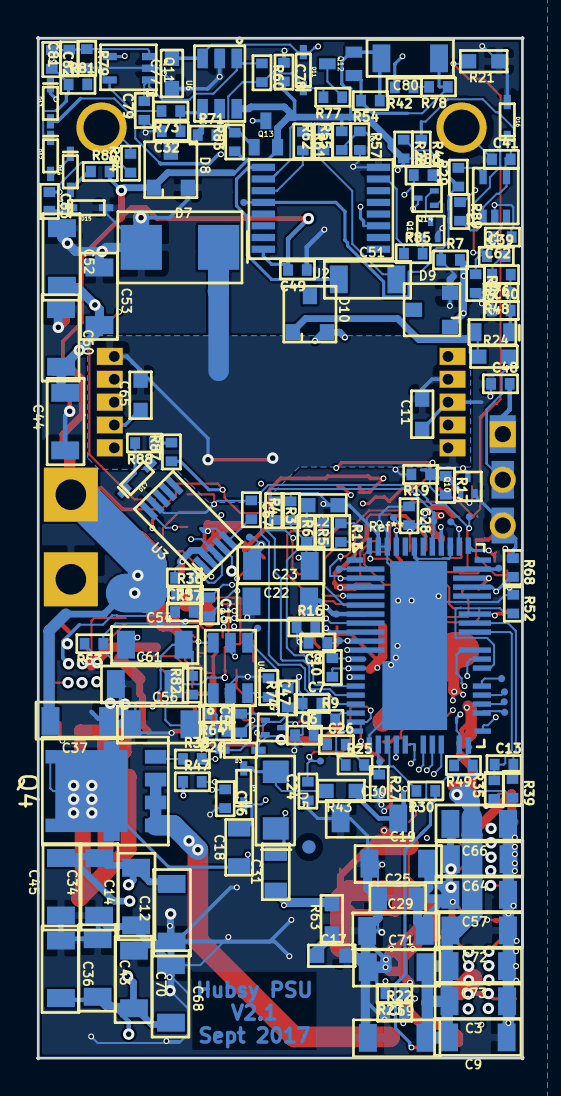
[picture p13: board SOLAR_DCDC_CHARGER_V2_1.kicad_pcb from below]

Board: 6 copper layers, 27.0 x 56.8 mm, 241 parts (175 on the bottom side), 117 nets.
